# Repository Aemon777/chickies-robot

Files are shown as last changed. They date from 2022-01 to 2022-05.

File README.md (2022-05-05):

# Chic-Fil-A robot project.
The primary goal of this project is to develop a robot capable of rolling from inside the lower ENS to the CFA building and back.

# Catkin_ws
This is our catkin workspace for ROS, holding our code relating to ROS. The bulk of our project code is located here.

# Playground
This folder should be used primarily for messing around and testing new ideas and systems. Our primary microcontroller scripts are in thihs folder.

# Resources
This folder is intended for all files not pertaining directly to running the robot. Right now this includes 3D print files, tutorials for project processes, and sample code. It also contains our comports.yaml file which compiles all Serial access data for the robot--don't move it without finding all locations it is referenced first.

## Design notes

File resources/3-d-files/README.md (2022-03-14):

File for 3D-printed files needed for the robot.

# Folders:
Arm_Models - designed models for parts of the scissor lift  
major_parts - integral parts of the robot  
minor_parts - non-integral parts of the robot, for convenience or looks  
old_parts - no longer used parts  
reference_parts - component models for measurement reference

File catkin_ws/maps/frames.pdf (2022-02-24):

view_frames Result

Recorded at time: 1645314775.255552

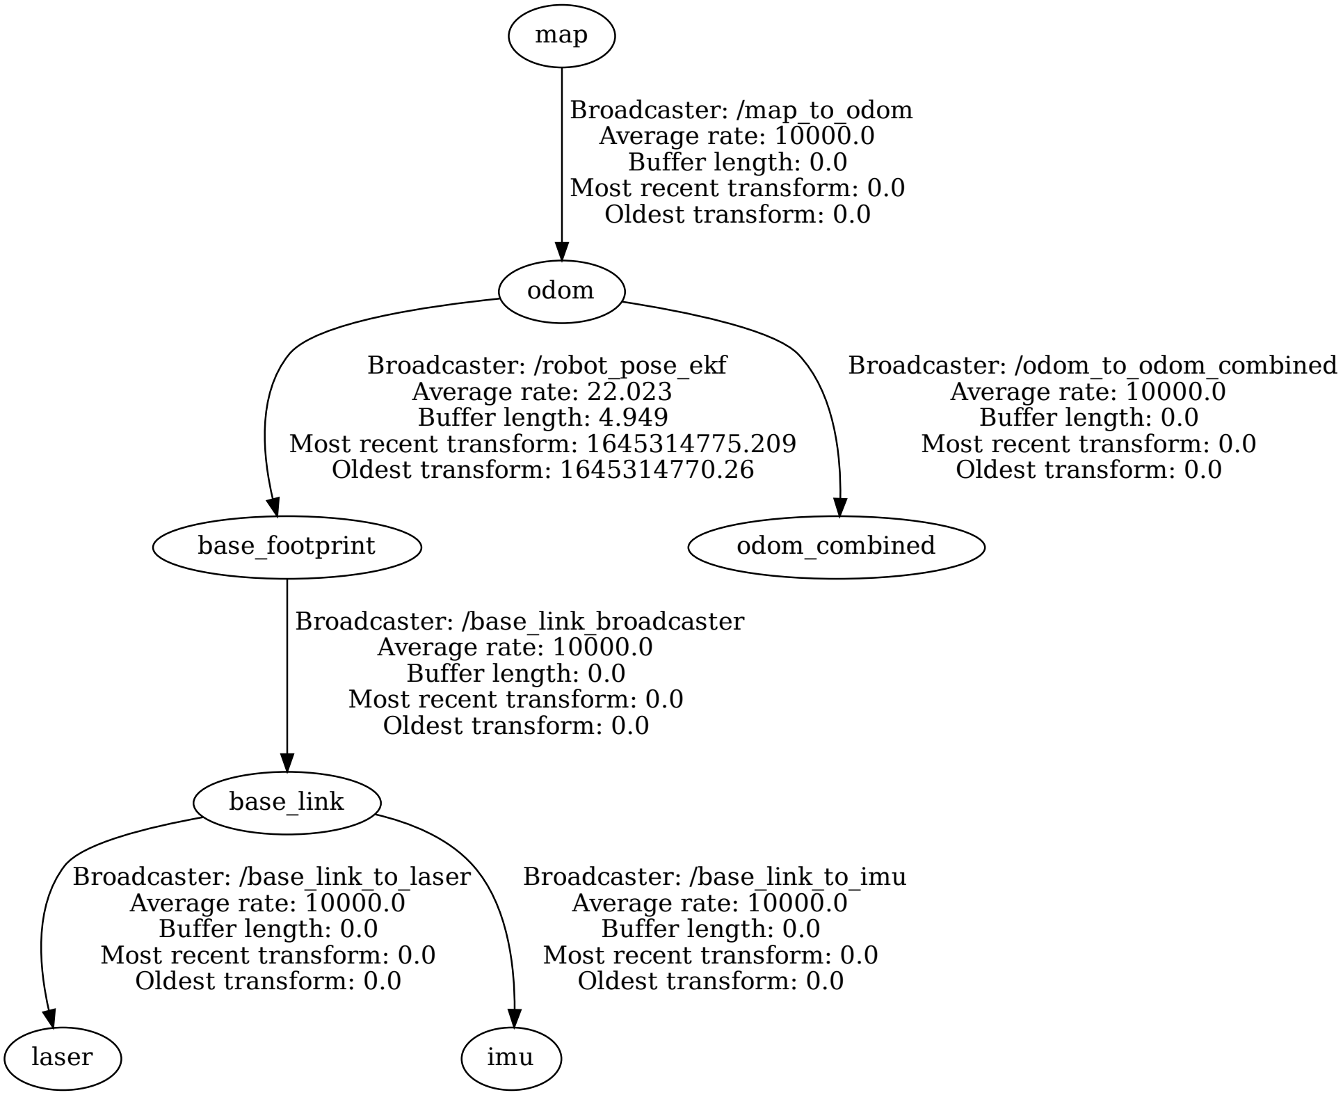
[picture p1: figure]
base_link; laser; Broadcaster: /base_link_to_laser Average rate: 10000.0 Buffer length: 0.0 Most recent transform: 0.0 Oldest transform: 0.0; imu; Broadcaster: /base_link_to_imu Average rate: 10000.0 Buffer length: 0.0 Most recent transform: 0.0 Oldest transform: 0.0; base_footprint; Broadcaster: /base_link_broadcaster Average rate: 10000.0 Buffer length: 0.0 Most recent transform: 0.0 Oldest transform: 0.0; map; odom; Broadcaster: /map_to_odom Average rate: 10000.0 Buffer length: 0.0 Most recent transform: 0.0 Oldest transform: 0.0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

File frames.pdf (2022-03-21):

view_frames Result

Recorded at time: 1647888612.2545614

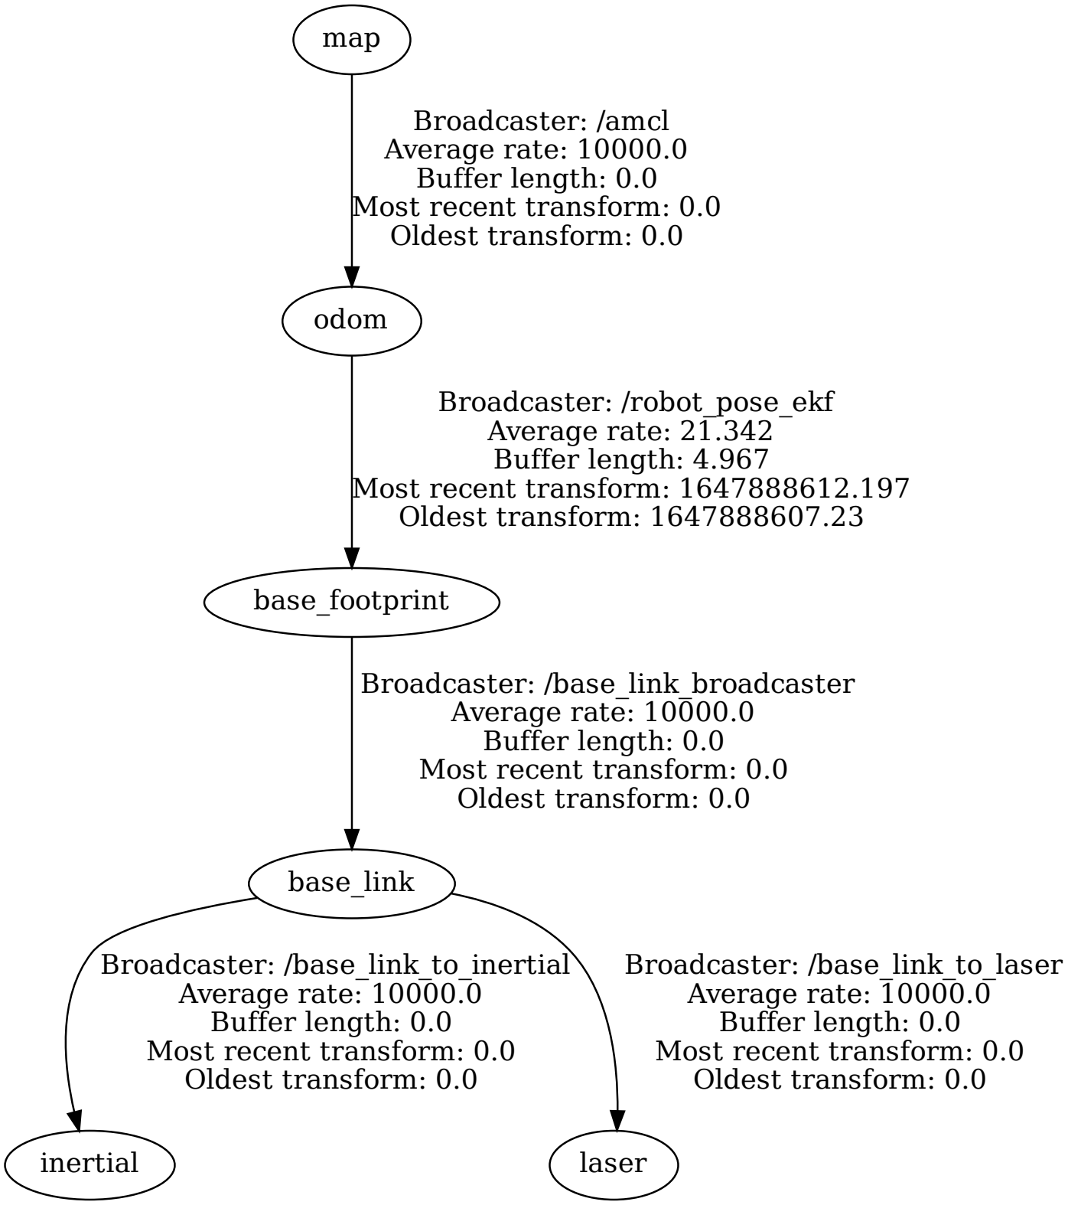
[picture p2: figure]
map; odom; Broadcaster: /amcl Average rate: 10000.0 Buffer length: 0.0 Most recent transform: 0.0 Oldest transform: 0.0; base_footprint; Broadcaster: /robot_pose_ekf Average rate: 21.342 Buffer length: 4.967 Most recent transform: 1647888612.197 Oldest transform: 1647888607.23; base_link; inertial; Broadcaster: /base_link_to_inertial Average rate: 10000.0 Buffer length: 0.0 Most recent transform: 0.0 Oldest transform: 0.0; laser; Broadcaster: /base_link_to_laser Average rate: 10000.0 Buffer length: 0.0 Most recent transform: 0.0 Oldest transform: 0.0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

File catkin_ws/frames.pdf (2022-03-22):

view_frames Result

Recorded at time: 1647988575.652083

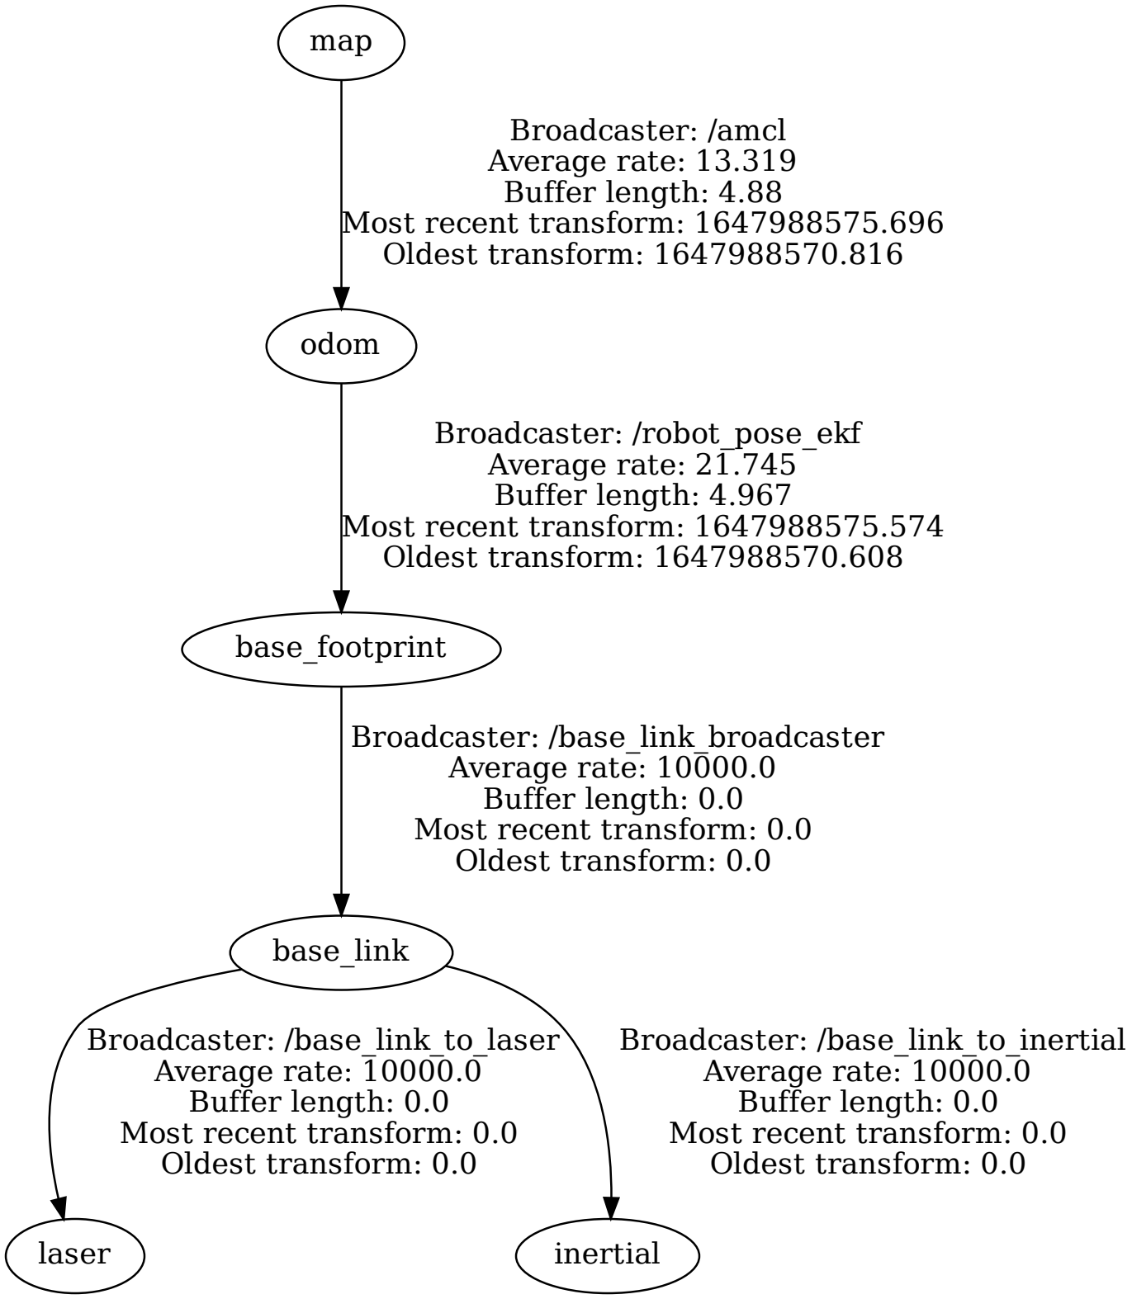
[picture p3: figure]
base_link; laser; Broadcaster: /base_link_to_laser Average rate: 10000.0 Buffer length: 0.0 Most recent transform: 0.0 Oldest transform: 0.0; inertial; Broadcaster: /base_link_to_inertial Average rate: 10000.0 Buffer length: 0.0 Most recent transform: 0.0 Oldest transform: 0.0; base_footprint; Broadcaster: /base_link_broadcaster Average rate: 10000.0 Buffer length: 0.0 Most recent transform: 0.0 Oldest transform: 0.0; odom; Broadcaster: /robot_pose_ekf Average rate: 21.745 Buffer length: 4.967 Most recent transform: 1647988575.574 Oldest transform: 1647988570.608; map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

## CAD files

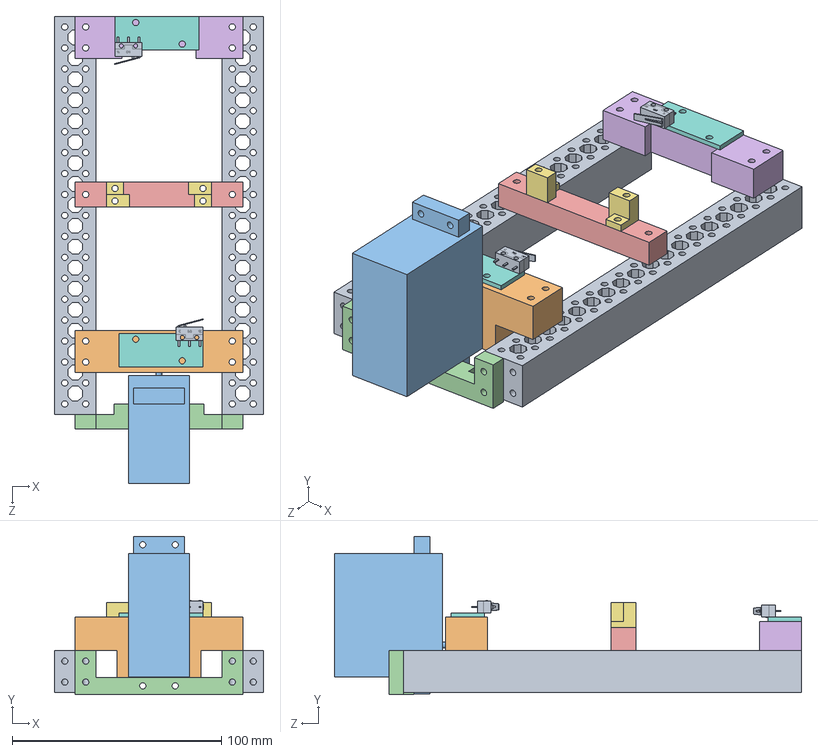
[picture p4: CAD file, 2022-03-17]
Lift_Model.SLDASM
100.0 x 75.6 x 223.0 mm
Beam_Made x 2
servo_holder
BeefyServo
BeefyHolder
slider_made
Rear_Screw_Mount_made
limiters_made x 2
limit_stand x 2
LimitSwitch x 2

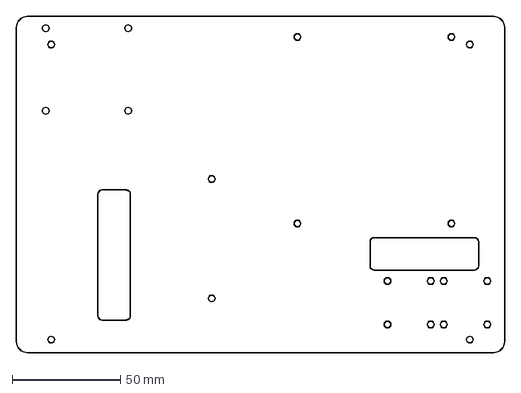
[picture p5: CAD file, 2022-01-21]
resources/3-d-files/major_parts/chassismainmountplane.dxf
225.0 x 155.0 mm

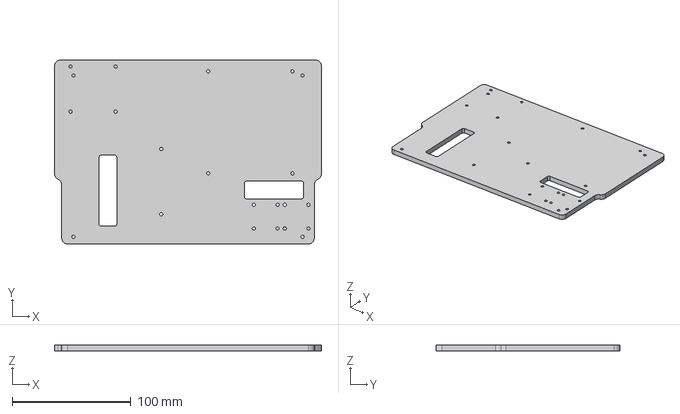
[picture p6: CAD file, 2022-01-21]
resources/3-d-files/major_parts/mainchassismountplanedrawing v2.step
225.0 x 155.0 x 5.00 mm

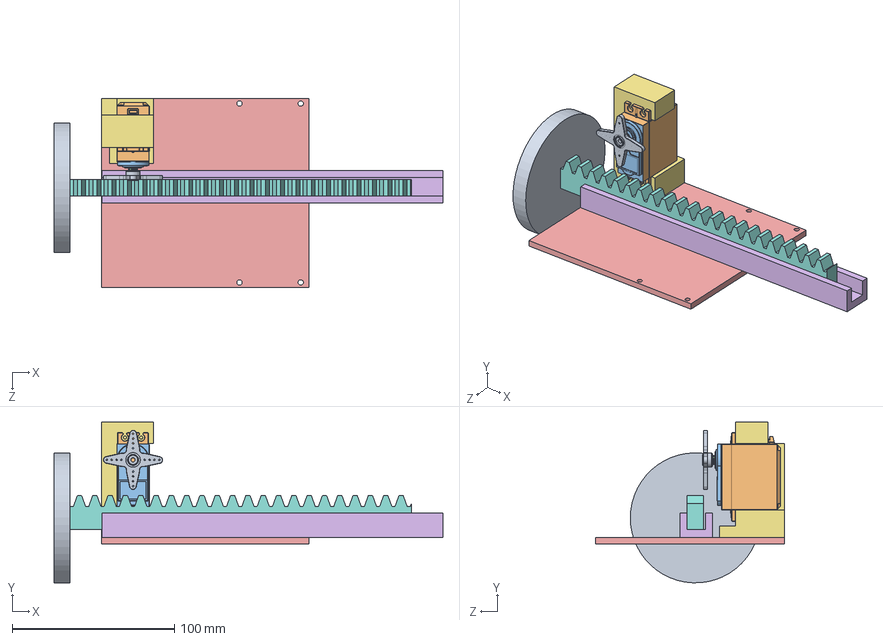
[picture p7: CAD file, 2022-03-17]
resources/3-d-files/Arm_Models/Rack and Gear Assembly.SLDASM
239.4 x 98.9 x 116.1 mm
Aspa-creu-Axix holder.step
Servo Futaba S3003.step
Servo Futaba S3003-0.step
Servo Futaba S3003-1.step
Base
Sider
Servo Holder
Rack Extend
ChickiesLogo

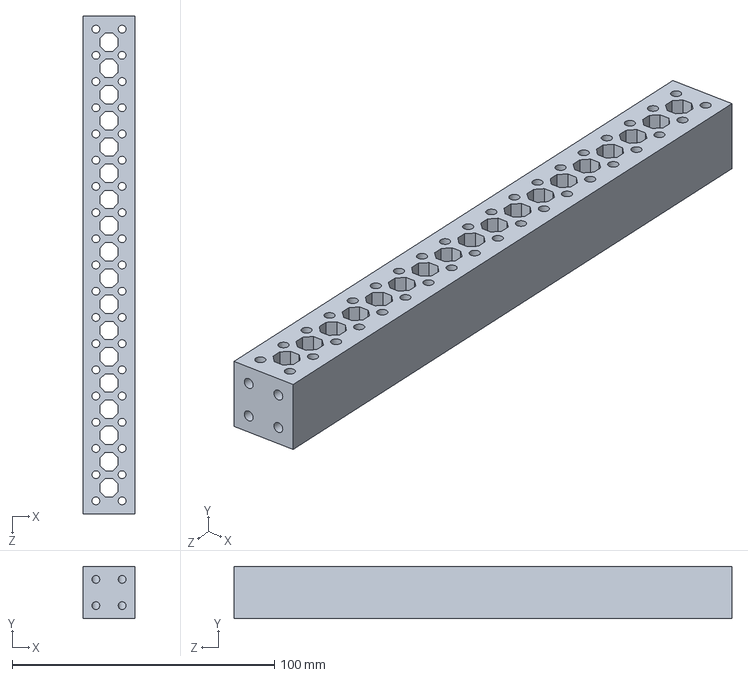
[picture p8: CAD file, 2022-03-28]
resources/3-d-files/Arm_Models/Beam_Made.SLDPRT
20.0 x 20.0 x 190.0 mm

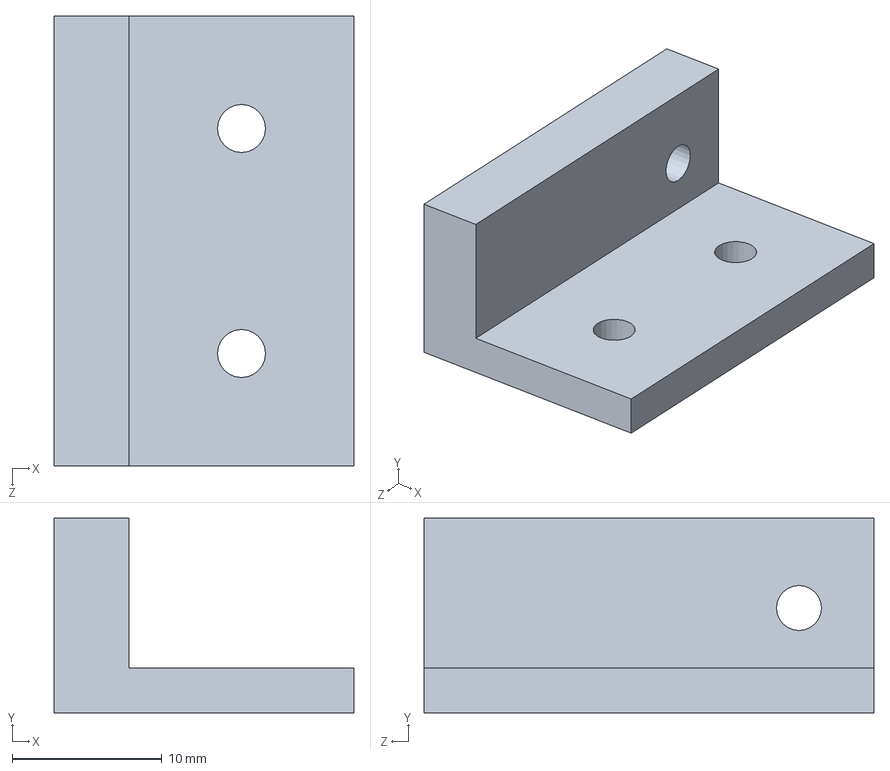
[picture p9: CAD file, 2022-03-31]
resources/3-d-files/FCU-Part-Files/Hinge Right.SLDPRT
20.0 x 13.0 x 30.0 mm

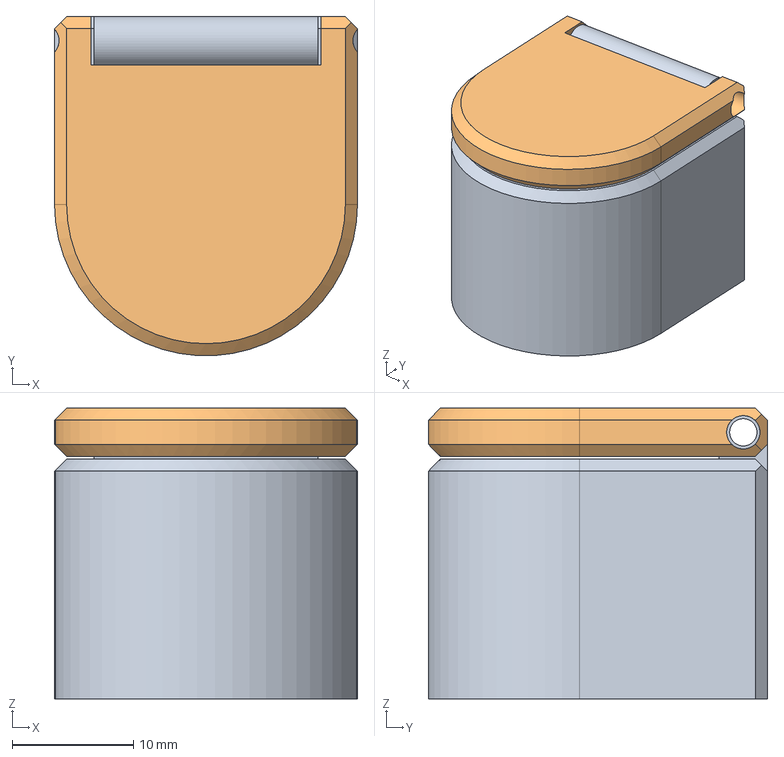
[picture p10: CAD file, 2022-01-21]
resources/3-d-files/minor_parts/pipowerbuttoncover v2.step
25.0 x 28.0 x 24.0 mm

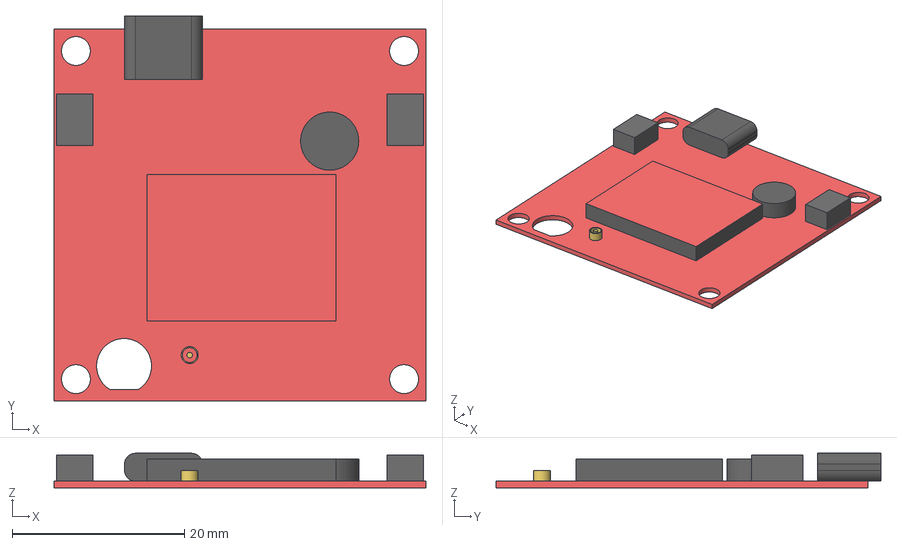
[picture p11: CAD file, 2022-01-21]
resources/3-d-files/reference_models/SparkFun GPS-RTK2 Board - ZED-F9P v1.step
43.2 x 44.7 x 4.01 mm

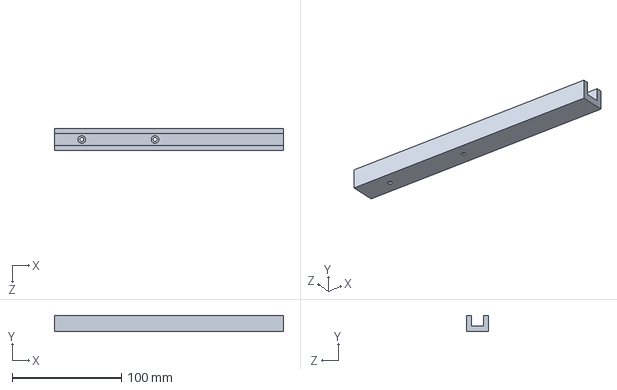
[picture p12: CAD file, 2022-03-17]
resources/3-d-files/Arm_Models/Sider.SLDPRT
210.0 x 15.0 x 20.0 mm

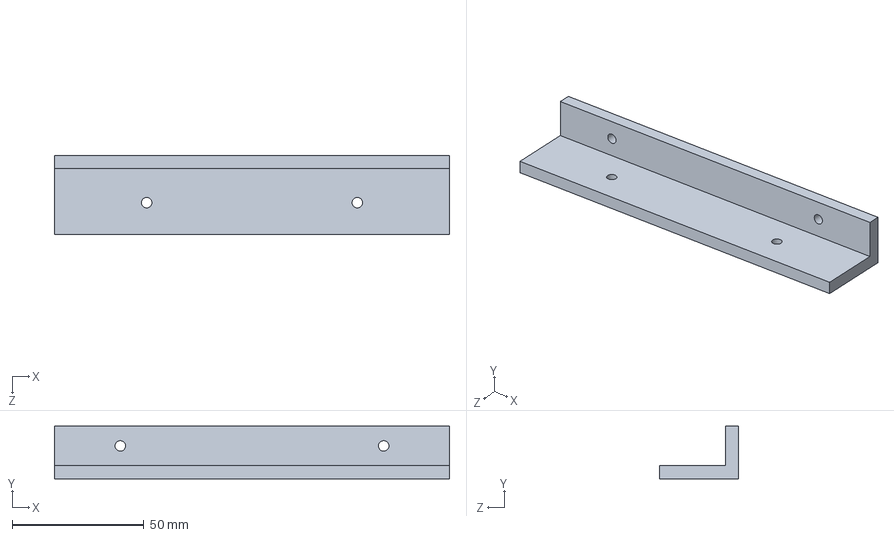
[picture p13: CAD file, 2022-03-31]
resources/3-d-files/FCU-Part-Files/Top-side Bracket.SLDPRT
150.0 x 20.0 x 30.0 mm

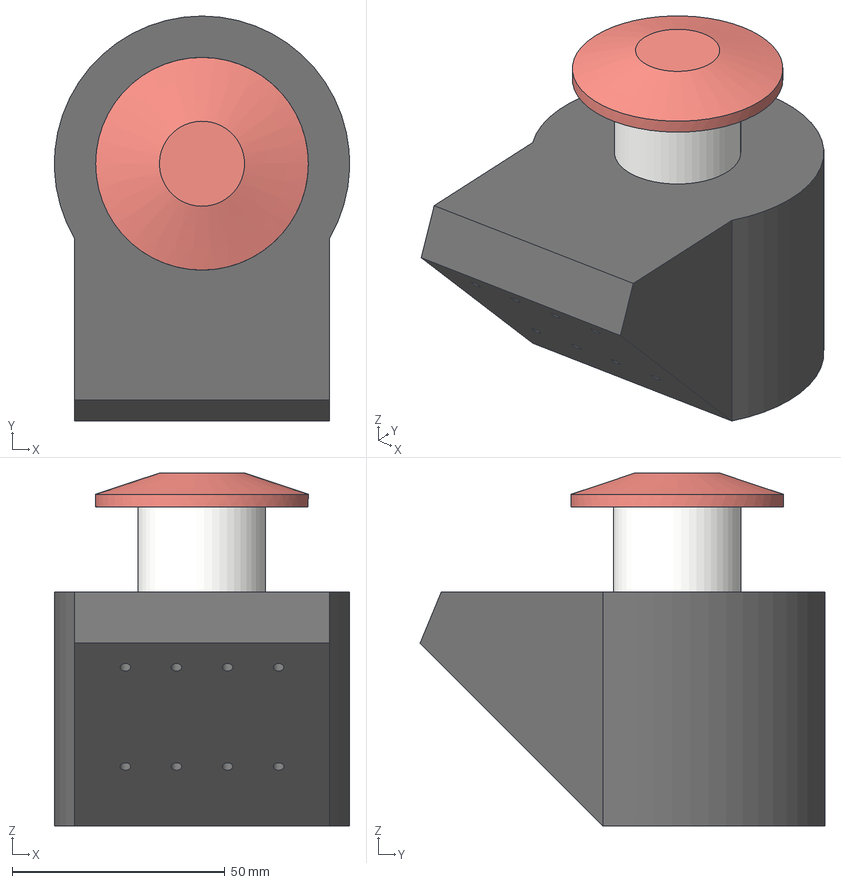
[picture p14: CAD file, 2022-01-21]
resources/3-d-files/major_parts/Emergency Button Case v5.step
69.4 x 95.2 x 83.0 mm

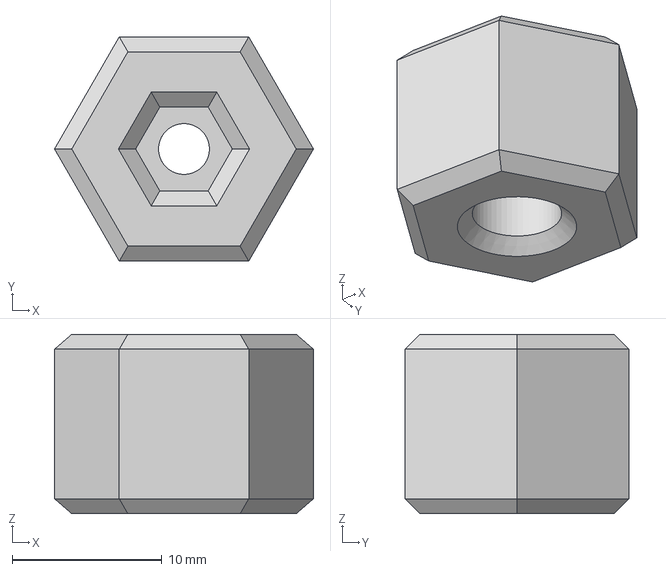
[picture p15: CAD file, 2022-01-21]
resources/3-d-files/minor_parts/frontmountknob v1.step
17.3 x 15.0 x 12.0 mm

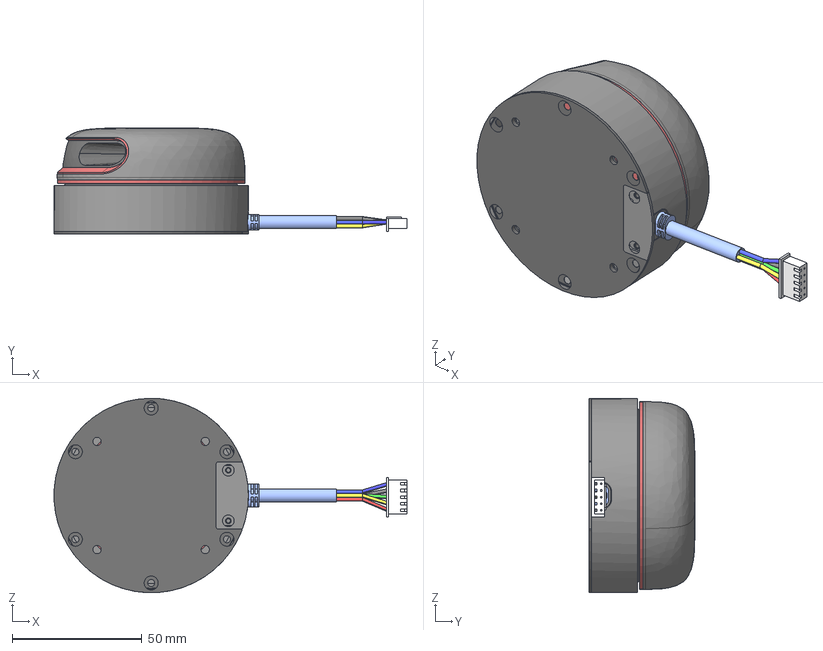
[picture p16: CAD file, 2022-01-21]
resources/3-d-files/reference_models/rplidar-a2m4-r1 v1.step
136.2 x 40.8 x 75.0 mm
µ×¸Ç
±àÂë³ÝÍâ¿Ç
Ðý×ªÆ½Ì¨
LENS_1.6
KEY_1.6
BAT_COVER_19
·â¸Ç
¼¤¹â·¢ÉäÍ·
¾µÍ·
4pinÏßÀÂ
½ÓÏß¶Ë¸Ç
6p ²åÍ·
Áã¼þ4^Íâ½ÓÏßÕ ûÌå
5pin 2.54²åÍ·
Áã¼þ1^Íâ½ÓÏßÕ ûÌå

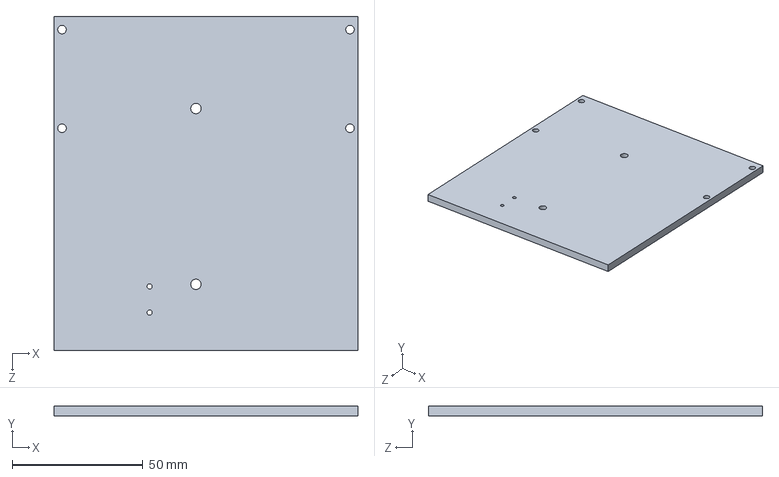
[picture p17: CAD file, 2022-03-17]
resources/3-d-files/Arm_Models/Base2.SLDPRT
116.1 x 3.90 x 127.7 mm

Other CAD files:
resources/3-d-files/FCU-Part-Files/hinge.SLDPRT
resources/3-d-files/major_parts/monitor mount lasercut v3.step
resources/3-d-files/minor_parts/motorcontrollermount v1.step
resources/3-d-files/Arm_Models/BeefyHolder.SLDPRT
resources/3-d-files/Arm_Models/BeefyServo.SLDPRT
resources/3-d-files/Arm_Models/ChickiesLogo.SLDPRT
resources/3-d-files/Arm_Models/Gear v1.SLDPRT
resources/3-d-files/Arm_Models/LimitSwitch.SLDPRT
resources/3-d-files/Arm_Models/Rack Extend.SLDPRT
resources/3-d-files/Arm_Models/Rear_Screw_Mount_made.SLDPRT
resources/3-d-files/Arm_Models/Servo Futaba S3003.SLDPRT
resources/3-d-files/Arm_Models/Servo Holder.SLDPRT
resources/3-d-files/Arm_Models/limit_stand.SLDPRT
resources/3-d-files/Arm_Models/limiters_made.SLDPRT
resources/3-d-files/Arm_Models/servo_holder.SLDPRT
resources/3-d-files/Arm_Models/slider_made.SLDPRT
resources/3-d-files/FCU-Part-Files/Anchor Left.SLDPRT
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

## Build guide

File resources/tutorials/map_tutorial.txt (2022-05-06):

THIS TUTORIAL OBSOLETE, USE 
    Mapping with gmapping.txt

Creating a map:
    roslaunch rplidar_ros rplidar.launch
    roslaunch hector_slam_launch tutorial.launch
    Observe RVIZ
    Jiggle robot until you are happy with the map
    Go to the folder where you want your map
    rosrun map_server map_saver -f <map_name>

Running a map   
    Go to the folder where you saved your map
    rosrun map_server map_server <map_name>.yaml

#set up system for remote monitoring of ROS topics
#export ROS_MASTER_URI=http://10.243.240.150:11311
#export ROS_IP=10.243.240.150
#export ROS_HOSTNAME=10.243.240.150

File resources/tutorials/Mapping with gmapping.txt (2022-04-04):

Using the gmapping process has two steps

    1.  Build a bag file for the gmapping process to run on
        The gmapping slam process runs by parsing data stored in a bag file
        This means the data gathering is done ahead of time, so we need to set up data gathering

        A.  Turn on the remote control. This is so the next step won't send the robot spinning.
        B.  run 
                "roslaunch system_launch make_map.launch"
            This is the launch file that runs all systems needed for the rosbag file
        C.  run "rviz"
        D.  In rviz, go to the upper left and change global frame to odom
        E.  Then give the robot an initial pose. Anywhere will do. Set it parallel to a grid line?
        F.  Once you've done this, run "rostopic echo tf" to make sure the /robot_pose_ekf/odom_combined is working
                You should see some sort of tf data for odom to base_footprint
        G.  Go into the chickies-robot/catkin_ws/maps folder and run   
                "rosbag record -O <file_name> /scan /tf /tf_static"
        H.  Drive the robot through the area you want mapped.
    
    2.  Run slam while replaying the bag file
        A.  Run "rosparam set use_sim_time true"
        B.  From anywhere, run "rosrun gmapping slam_gmapping scan:=scan"
        C.  From the chickies-robot/catkin_ws/maps directory, run
                rosbag play --clock <file_name>.bag
        D.  When the bag has played all the way out, run
                rosrun map_server map_saver -f <file_name>

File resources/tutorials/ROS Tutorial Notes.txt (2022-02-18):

Links
    Generalized ROS tutorial: http://wiki.ros.org/ROS/Tutorials
    rospy tutorials: http://wiki.ros.org/rospy_tutorials?distro=noetic
    tf tutorials: http://wiki.ros.org/tf/Tutorials 

Random notes
    Master manages the various topics that exist
    Nodes run code, publish and subscribe
    Topics are basically names of buses that can be created by any node that publishes or subscribes to them -- tracked by Master in roscore

catkin process
    catkin_create_pkg <name> [dependencies]
        Command for creating a catkin package, should be performed in the src file of your catkin workspace
    catkin_make
        Should be run from your workspace folder after doing basically anything

Node types that have come up
    turtlesim turtlesim_node
        This makes a turtle that can move around, random design, kinda cute ngl
    turtle_turtlesim teleop_key
        Finds turtle and commands it to do stuff (publishing to the /)
    rqt_graph rqt_graph
        Makes a graph that tracks current nodes and topic connections
    rqt_plot rqt_plot
        Makes a plot tracking data published on a given topic
        
Commands I decided to write down
    roscore
        roscore
            Starts the roscore, needed before anything really happens
    rosnode
        rosnode list 
            Shows all the current rosnodes running
        rosnode info <node_name>
            Shows specific info about selected node
        rosnode ping <node_name>
    rosrun
        rosrun <package_name> <node_name> {can add modifiers like __name:=turtle1}
            Creates a node of the node_name type from package_name
    rostopic
        rostopic echo <topic>
            Echoes all commands posted on a given topic
        rostopic list
            Lists topics
        rostopic type <topic>
            Yields the type of messages meant to be sent over the specified topic
        rostopic pub <options> <topic> <msg_type> <args>
            Publishes a message of the given type to the specified topic with the given args
                Common options: --once/-1 to only send the message for like 3 seconds
                    -r # to have the command repeat at a frequency given by # Hertz
        rostopic hz <topic>
            Shows rate of publish on that topic
        rostopic type <topic> | rosmsg show
            Prints the format of messages to be published on the given topic
    rosmsg
        rosmsg show <message_type>
            Shows the format of the specified message type
    rosservice
        rosservice list
            Lists services
        rosservice type <service> <options>
            Shows the parameter type of the given service 
            Notable suffix: | rossrv show   
                Shows format for the type
    rosparam - background parameters stored by ROS
        rosparam list
            Take a guess
        rosparam set <param-name>
        rosparam get <param-name>
            Mutator and accessor for a given param
        rosparam get /
            Displays all current parameters and values
        rosparam dump <file-name.yaml> [namespace]
            Sends all current parameters to the given .yaml file, in the optional namespace
        rosparam load <file-name.yaml> [namespace]
            Loads parameters form yaml file, to the optional namespace

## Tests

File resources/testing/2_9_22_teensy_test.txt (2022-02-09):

2/9/22, afternoon
Blackburn finished a draft of Teensy script that uses a dynamic smoother to attempt to reach
    target velocities for each wheel side

Murphy now testing the Teensy and motor controller interaction

    Conclusion 1: Over 40 seconds of messages from motor_driver.py cause the Teensy to enter a bad state
        Both wheels go into a state of full reverse and do not respond to commands in any way
    Conclusion 2: Door-side wheels (not sure which side that is left/right) can reach a bad state
        Sometimes the ds wheels do not respond to commands to slow down, only to go the opposite direction
        Cannot reproduce this on demand
    Conclusion 3: Filtering is effective
        Robot moves and changes directions smoothly under load
    
Test 1
    Accelerate from 0 to full throttle -- wait
        Good until radio receiver jumped the tracks
        Then system broke, Teensy reversed direction, stopped listening to commands from pi
        Disconnected Teensy from power
Test 2
    Accelerate from 0 to full throttle -- wait
        Radio receiver again broke system
        Note: radio receiver does not break unless sending some kind of signal
Test 3
    Accelerate from 0 to full throttle -- wait
        Good about 10 seconds
    Decelerate back to 0
        Bad: left side continued spinning
    Accelerate back to full
        Radio receiver code broke, causing full reverse
        Note: restarting systems does not fix Teensy state after this
Test 4
    Accelerate to about half
        Both motors Good
    Attempt to decelerate
        Left wheel moves forward as before, not decelerating
    Attempt to turn
        Left wheel decelerates when told to go in the reverse direction!
        Looks like some problem with left wheel deceleration command code
    Both wheels go to reverse without radio receiver failure
        Looks like after some amount of time with motor_driver.py running, the filter breaks
        Maybe a parsing issue?
Test 5
    Just turned motor_driver.py on and left it for a while, 3 times
        Trial 1: full reverse at about 39 seconds
        Trial 2: full reverse at about 40 seconds
        Trial 3: full reverse at about 42 seconds
        Clear pattern observed
Test 6
    Turned Teensy on, waited over 3 minutes
    No reverse observed
Test 7
    Turned motor_driver.py on then immediately off, set timer
        No effect
    Turned it on and off repeatedly until over 60 seconds of uptime had accumulated
        No effect
Test 8
    Turned robot on and drove it in short bursts (battery power)
    Acceleration to dead run quite smooth
    Robot well able to move from dead forward to dead reverse, transition smooth
    Turning is excellent, easy to move between curve, pivot, swivel

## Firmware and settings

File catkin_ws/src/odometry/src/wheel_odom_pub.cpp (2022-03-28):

/*
 * Automatic Addison
 * Date: May 20, 2021
 * ROS Version: ROS 1 - Melodic
 * Website: https://automaticaddison.com
 * Publishes odometry information for use with robot_pose_ekf package.
 *   This odometry information is based on wheel encoder tick counts.
 * Subscribe: ROS node that subscribes to the following topics:
 *  right_ticks : Tick counts from the right motor encoder (std_msgs/Int16)
 * 
 *  left_ticks : Tick counts from the left motor encoder  (std_msgs/Int16)
 * 
 *  initial_2d : The initial position and orientation of the robot.
 *               (geometry_msgs/PoseStamped)
 *
 * Publish: This node will publish to the following topics:
 *  odom_data_euler : Position and velocity estimate. The orientation.z 
 *                    variable is an Euler angle representing the yaw angle.
 *                    (nav_msgs/Odometry)
 *  odom_data_quat : Position and velocity estimate. The orientation is 
 *                   in quaternion format.
 *                   (nav_msgs/Odometry)
 * Modified from Practical Robotics in C++ book (ISBN-10 : 9389423465)
 *   by Lloyd Brombach
 */
 
// Include various libraries
#include "ros/ros.h"
#include "std_msgs/Int64.h"
#include <nav_msgs/Odometry.h>
#include <geometry_msgs/PoseStamped.h>
#include <tf2/LinearMath/Quaternion.h>
#include <tf2_ros/transform_broadcaster.h>
#include <cmath>
 
// Create odometry data publishers
ros::Publisher odom_data_pub;
ros::Publisher odom_data_pub_quat;
nav_msgs::Odometry odomNew;
nav_msgs::Odometry odomOld;
 
// Initial pose
const double initialX = 0.0;
const double initialY = 0.0;
const double initialTheta = 0.00000000001;
const double PI = 3.141592;
 
// Robot physical constants
//const double TICKS_PER_REVOLUTION = 1; // For reference purposes.
//const double WHEEL_RADIUS = 0.033; // Wheel radius in meters
const double WHEEL_BASE = 0.4; // Center of left tire to center of right tire
const double TICKS_PER_METER = 138000*3; // Original was 2800
const double SLIPPAGE_CORRECTION = 0.6757; // Turning correction constant due to differential slippage
 
// Distance both wheels have traveled
double distanceLeft = 0;
double distanceRight = 0;
 
// Flag to see if initial pose has been received
bool initialPoseRecieved = false;
 
using namespace std;
 
// Get initial_2d message from either Rviz clicks or a manual pose publisher
void set_initial_2d(const geometry_msgs::PoseStamped &rvizClick) {
 
  odomOld.pose.pose.position.x = rvizClick.pose.position.x;
  odomOld.pose.pose.position.y = rvizClick.pose.position.y;
  odomOld.pose.pose.orientation.z = rvizClick.pose.orientation.z;
  initialPoseRecieved = true;
}
 
// Calculate the distance the left wheel has traveled since the last cycle
void Calc_Left(const std_msgs::Int64& leftCount) {
 
  static int lastCountL = 0;
  if(leftCount.data != 0 && lastCountL != 0) {
         
    int leftTicks = (leftCount.data - lastCountL);
 
    if (leftTicks > 10000) {
      leftTicks = 0 - (65535 - leftTicks);
    }
    else if (leftTicks < -10000) {
      leftTicks = 65535-leftTicks;
    }
    else{}
    distanceLeft = leftTicks/TICKS_PER_METER;
  }
  lastCountL = leftCount.data;
}
 
// Calculate the distance the right wheel has traveled since the last cycle
void Calc_Right(const std_msgs::Int64& rightCount) {
   
  static int lastCountR = 0;
  if(rightCount.data != 0 && lastCountR != 0) {
 
    int rightTicks = rightCount.data - lastCountR;
     
    if (distanceRight > 10000) {
      distanceRight = (0 - (65535 - distanceRight))/TICKS_PER_METER;
    }
    else if (rightTicks < -10000) {
      rightTicks = 65535 - rightTicks;
    }
    else{}
    distanceRight = rightTicks/TICKS_PER_METER;
  }
  lastCountR = rightCount.data;
}
 
// Publish a nav_msgs::Odometry message in quaternion format
void publish_quat() {
 
  tf2::Quaternion q;
         
  q.setRPY(0, 0, odomNew.pose.pose.orientation.z);
 
  nav_msgs::Odometry quatOdom;
  quatOdom.header.stamp = odomNew.header.stamp;
  quatOdom.header.frame_id = "odom";
  quatOdom.child_frame_id = "base_link";
  quatOdom.pose.pose.position.x = odomNew.pose.pose.position.x;
  quatOdom.pose.pose.position.y = odomNew.pose.pose.position.y;
  quatOdom.pose.pose.position.z = odomNew.pose.pose.position.z;
  quatOdom.pose.pose.orientation.x = q.x();
  quatOdom.pose.pose.orientation.y = q.y();
  quatOdom.pose.pose.orientation.z = q.z();
  quatOdom.pose.pose.orientation.w = q.w();
  quatOdom.twist.twist.linear.x = odomNew.twist.twist.linear.x;
  quatOdom.twist.twist.linear.y = odomNew.twist.twist.linear.y;
  quatOdom.twist.twist.linear.z = odomNew.twist.twist.linear.z;
  quatOdom.twist.twist.angular.x = odomNew.twist.twist.angular.x;
  quatOdom.twist.twist.angular.y = odomNew.twist.twist.angular.y;
  quatOdom.twist.twist.angular.z = odomNew.twist.twist.angular.z;
 
  for(int i = 0; i<36; i++) {
    if(i == 0 || i == 7 || i == 14) {
      quatOdom.pose.covariance[i] = 0.1;
     }
     else if (i == 21 || i == 28 || i== 35) {
       quatOdom.pose.covariance[i] += 0.2;
     }
     else {
       quatOdom.pose.covariance[i] = 0;
     }
  }
 
  odom_data_pub_quat.publish(quatOdom);
}
 
// Update odometry information
void update_odom() {
 
  // Calculate the average distance
  double cycleDistance = (distanceRight + distanceLeft) / 2;
   
  // Calculate the number of radians the robot has turned since the last cycle
  double cycleAngle = asin((distanceRight-distanceLeft)/WHEEL_BASE);
  //cycleAngle = cycleAngle * 0.01;
 
  // Average angle during the last cycle
  double avgAngle = cycleAngle/2 + odomOld.pose.pose.orientation.z;
     
  if (avgAngle > PI) {
    avgAngle -= 2*PI;
  }
  else if (avgAngle < -PI) {
    avgAngle += 2*PI;
  }
  else{}
 
  // Calculate the new pose (x, y, and theta)
  odomNew.pose.pose.position.x = odomOld.pose.pose.position.x + cos(avgAngle)*cycleDistance;
  odomNew.pose.pose.position.y = odomOld.pose.pose.position.y + sin(avgAngle)*cycleDistance;
  odomNew.pose.pose.orientation.z = cycleAngle + odomOld.pose.pose.orientation.z;
 
  // Prevent lockup from a single bad cycle
  if (isnan(odomNew.pose.pose.position.x) || isnan(odomNew.pose.pose.position.y)
     || isnan(odomNew.pose.pose.position.z)) {
    odomNew.pose.pose.position.x = odomOld.pose.pose.position.x;
    odomNew.pose.pose.position.y = odomOld.pose.pose.position.y;
    odomNew.pose.pose.orientation.z = odomOld.pose.pose.orientation.z;
  }
 
  // Make sure theta stays in the correct range
  if (odomNew.pose.pose.orientation.z > PI) {
    odomNew.pose.pose.orientation.z -= 2 * PI;
  }
  else if (odomNew.pose.pose.orientation.z < -PI) {
    odomNew.pose.pose.orientation.z += 2 * PI;
  }
  else{}
 
  // Compute the velocity
  odomNew.header.stamp = ros::Time::now();
  odomNew.twist.twist.linear.x = cycleDistance/(odomNew.header.stamp.toSec() - odomOld.header.stamp.toSec());
  odomNew.twist.twist.angular.z = cycleAngle/(odomNew.header.stamp.toSec() - odomOld.header.stamp.toSec());
 
  // Save the pose data for the next cycle
  odomOld.pose.pose.position.x = odomNew.pose.pose.position.x;
  odomOld.pose.pose.position.y = odomNew.pose.pose.position.y;
  odomOld.pose.pose.orientation.z = odomNew.pose.pose.orientation.z;
  odomOld.header.stamp = odomNew.header.stamp;
 
  // Publish the odometry message
  odom_data_pub.publish(odomNew);
}
 
int main(int argc, char **argv) {
   
  // Set the data fields of the odometry message
  odomNew.header.frame_id = "odom";
  odomNew.pose.pose.position.z = 0;
  odomNew.pose.pose.orientation.x = 0;
  odomNew.pose.pose.orientation.y = 0;
  odomNew.twist.twist.linear.x = 0;
  odomNew.twist.twist.linear.y = 0;
  odomNew.twist.twist.linear.z = 0;
  odomNew.twist.twist.angular.x = 0;
  odomNew.twist.twist.angular.y = 0;
  odomNew.twist.twist.angular.z = 0;
  odomOld.pose.pose.position.x = initialX;
  odomOld.pose.pose.position.y = initialY;
  odomOld.pose.pose.orientation.z = initialTheta;
 
  // Launch ROS and create a node
  ros::init(argc, argv, "ekf_odom_pub");
  ros::NodeHandle node;
 
  // Subscribe to ROS topics
  ros::Subscriber subForRightCounts = node.subscribe("right_ticks", 100, Calc_Right, ros::TransportHints().tcpNoDelay());
  ros::Subscriber subForLeftCounts = node.subscribe("left_ticks", 100, Calc_Left, ros::TransportHints().tcpNoDelay());
  ros::Subscriber subInitialPose = node.subscribe("initial_2d", 1, set_initial_2d);
 
  // Publisher of simple odom message where orientation.z is an euler angle
  odom_data_pub = node.advertise<nav_msgs::Odometry>("odom_data_euler", 100);
 
  // Publisher of full odom message where orientation is quaternion
  odom_data_pub_quat = node.advertise<nav_msgs::Odometry>("odom", 100);
 
  ros::Rate loop_rate(30); 
     
  while(ros::ok()) {
     
    if(initialPoseRecieved) {
      update_odom();
      publish_quat();
    }
    ros::spinOnce();
    loop_rate.sleep();
  }
 
  return 0;
}

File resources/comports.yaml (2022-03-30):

---
 GPS_PORT: "/dev/ZEDF9P"
 GPS_BAUDRATE: 9600
 RADIO_PORT: "/dev/RadioRX"
 RADIO_BAUDRATE: 115200
 TEENSY_ENCODERS_PORT: "/dev/Teensy_Encoders"
 TEENSY_ENCODERS_BAUDRATE: 115200
 TEENSY_ENCODERS_UPDATE_RATE: 10
 TEENSY_MOTORS_PORT: "/dev/Teensy_Motors"
 TEENSY_MOTORS_BAUDRATE: 115200
 TEENSY_MOTORS_UPDATE_RATE: 10
 NANO_IMU_PORT: "/dev/Micro_IMU"
 NANO_IMU_BAUDRATE: 115200
 NANO_IMU_UPDATE_RATE: 20

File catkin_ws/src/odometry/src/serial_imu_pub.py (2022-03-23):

import rospy
import serial
import sys
import yaml
from time import sleep
from std_msgs.msg import String
from std_msgs.msg import Float64
from sensor_msgs.msg import MagneticField,Imu

class imu_pub():
    def __init__(self):
        self.serialPort = ""
        with open('/home/ubuntu/chickies-robot/resources/comports.yaml', "r") as stream:
            try:
                params = yaml.safe_load(stream)
                self.serialPort=serial.Serial(params['NANO_IMU_PORT'],params['NANO_IMU_BAUDRATE'])
            except yaml.YAMLError as exc:
                print(exc)
        rospy.init_node('imu', anonymous=True)
        self.raw_pub = rospy.Publisher('imu_data', Imu, queue_size=10)
        self.mag_pub = rospy.Publisher('imu_mag', MagneticField, queue_size=10)
        self.rate = rospy.Rate(params['NANO_IMU_UPDATE_RATE'])
        rospy.loginfo(rospy.get_caller_id() + "  IMU node launched.")
        self.serialPort.flush()
        self.serialPort.reset_input_buffer()
        self.serialPort.reset_output_buffer()

    def spin(self):
        while not rospy.is_shutdown():
            try:
                self.serialPort.write('Q,**'.encode('utf-8'))
                read = self.serialPort.readline().decode('utf-8')
                data = read.split(',')
                if(data[0] == 'I' and len(data) == 11 and data[10] == '**\r\n'):
                    raw_msg = Imu()
                    raw_msg.header.stamp = rospy.Time.now()
                    raw_msg.header.frame_id = 'inertial'
                        
                    raw_msg.orientation.w = -1
                    raw_msg.orientation.x = 0
                    raw_msg.orientation.y = 0
                    raw_msg.orientation.z = 0
                        
                    raw_msg.linear_acceleration.x = float(data[1])
                    raw_msg.linear_acceleration.y = float(data[2])
                    raw_msg.linear_acceleration.z = -float(data[3])
                        
                    raw_msg.angular_velocity.x = float(data[4])
                    raw_msg.angular_velocity.y = float(data[5])
                    raw_msg.angular_velocity.z = float(data[6])
                        
                    #raw_msg.orientation_covariance[0] = -1
                    raw_msg.orientation_covariance = [-1,9000,9000,9000,9000,9000,9000,9000,9000]#[-1, 1, 1, 1, 1, 1, 1, 1, 1]#[-1,0,0,0,0,0,0,0,0]
                    #raw_msg.linear_acceleration_covariance[0] = -1
                    raw_msg.linear_acceleration_covariance = [0.0000599193, 0, 0, 0, 0.0000492518, 0, 0, 0, 0.000415205]
                    #raw_msg.angular_velocity_covariance[0] = -1
                    raw_msg.angular_velocity_covariance = [0.00001, 0, 0, 0, 0.00001, 0, 0, 0, 0.00001]
                    self.raw_pub.publish(raw_msg)
                        
                    mag_msg = MagneticField()
                    mag_msg.header.stamp = rospy.Time.now()
                    mag_msg.magnetic_field.x = float(data[7])
                    mag_msg.magnetic_field.y = float(data[8])
                    mag_msg.magnetic_field.z = float(data[9])
                    mag_msg.magnetic_field_covariance = [0.55498, 0, 0, 0, 0.943658, 0, 0, 0, 0.586553]
                    self.mag_pub.publish(mag_msg)
                    rospy.loginfo(raw_msg.linear_acceleration.z)

                self.rate.sleep()
            except serial.serialutil.SerialException:
                sleep(0.5)
            except Exception as ex:
                template = "An exception of type {0} occurred. Arguments:\n{1!r}"
                message = template.format(type(ex).__name__, ex.args)
                print(message)
                sleep(0.5) 
        self.serialPort.close()

if __name__ == '__main__':
    try:
        imu_pub = imu_pub()
        imu_pub.spin()
    except rospy.ROSInterruptException:
        pass

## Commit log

2021-08-27 staged new files
2021-10-02 Tried to update test file, getting error
    [motorInterface.py, nunchukMove.py]
2021-10-04 Adjusted pin numbers
2021-10-04 Nunchuck motor interface working rudimentarily.
2021-10-04 Fixed tuple-reassignment: turned into list
    [motorInterface.py]
2021-10-04 Fixed data type bug
    [motorInterface.py]
2021-10-04 Added debugging print statements
2021-10-04 Fixed print error
2021-10-04 Adjusted management, cleaned prints
2021-10-06 Got nunchuck based movement working, added adjustment for left side stronger motor
2021-10-07 Added gitignore and moved files around to clean up directories
    [Emergency Button Case v2.f3d, LIDAR Model Stand.f3d, Rotary Encoder v1.f3d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]
2021-10-07 Moved EncoderScript into src
2021-10-11 Revert "Merge pull request #7 from Aemon777/Lidarstand"
    This reverts commit fbccfcbdd06eecdb1eeb1dc5681a660396ef24e9, reversing
    changes made to 3dc55e4b62bf97db24ce8babb7caa613af86cdbd.
2021-10-21 Add files via upload
    arduino file for current/voltmeter for battery
2021-10-21 Add files via upload
    actual arduino code to read voltage/current of battery
2021-10-21 Combined Encoder and vm/cm scripts
2021-10-28 added print statements
2021-10-30 added led test
2021-10-30 corrected pwm handling
2021-10-30 Adding a simple motor test
2021-10-30 Increased PWM
2021-11-08 Removed prints in zeroMotorTest.py
2021-11-08 Adjusted motor test to test encoder speed
2021-11-08 Fixed motorTest.py
2021-11-08 Adjusted PWM up
2021-11-08 motorTest output
2021-11-20 Added brake function
2021-12-10 added motor_controller package
2021-12-10 Removed testing_controller, added motor_controller
2021-12-10 Updated motor_controller package and CMakeLists
2021-12-10 Adjusted motor driver turning method
2021-12-10 fixed CMakeLists in motor_controller
2021-12-10 Removed ref to for_rev in motor_driver
2021-12-10 Adjusted radio_receiver steering value
2022-01-13 Add files via upload
    Step file for non-fusion360 CAD programs (eg solidworks)
2022-01-14 updated
    restructured files and added everything I had stored locally to the repo
    [Emergency Button Case v2.f3d, Emergency Button Case v5.f3d, Emergency Button Case v5.step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]
2022-01-22 Update motor_driver.py
    Cleaning up calls to various adjustments
2022-01-24 Corrected Python function calls
    [motor_driver.py]
2022-01-25 Wrote callbacks for wheel messages
2022-01-26 Final encoder
2022-02-02 "Adjusted motor driver variables"
2022-02-02 Moved files to legacy, updated motor_driver
2022-02-02 Added New Teensy PID Control
2022-02-03 adjusted motor driver
2022-02-03 Fixed driver/receiver
2022-02-03 update teensy code
2022-02-09 Added new motor controller
    Teensy_Custom_PID vscode project folder. It says PID, but it's not really P, I, or D, so the name will need to be changed later.
2022-02-10 Updated Teensy Script
    Teensy_Motor_Controller is the new (working) motor driver script.
2022-02-14 updated launch file and motor driver file top speeds
2022-02-16 new encoder stuff and sensor package
2022-02-18 switch from odom to odom_combined
2022-02-23 Reverted file swap between motor_driver and encoder_pub
    [encoder_pub.py, motor_driver.py]
2022-02-24 Added Arduino Scripts
2022-02-24 Updated comports syntax and motor_driver comports call
2022-02-25 updated encoder script for teensy
2022-02-25 added amcl
    [AMCL.cfg]
2022-03-04 Fixed motor_driver properly
2022-03-08 Update IMU covariance matrix
    updated the variance parameters to reflect actual testing rather than educated guesses
2022-03-17 Added arm part and assembly files
    [Base2.SLDPRT, ChickiesLogo.SLDPRT, Gear v1.SLDPRT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]
2022-03-18 updated frames
2022-03-18 transferring frames
2022-03-19 updated IMU publisher system
    IMU publishing is now synchronous between arduino and pi
2022-03-19 update encoder publisher
    encoder publisher is now synchronous between arduino and pi
2022-03-22 Adjusted local costmap global frame to map
2022-03-23 Added slippage correction and adjusted covariance
    [wheel_odom_pub.cpp]
2022-03-28 turned down velocity
2022-03-30 some testing
    [robot_localization_odom.yaml]
2022-03-31 Added FCU Part Files
    [Anchor Left.SLDPRT, Anchor Right.SLDPRT, Back Wall.SLDPRT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]
2022-05-06 cleaned odometry package
    [robot_localization_odom.yaml]
